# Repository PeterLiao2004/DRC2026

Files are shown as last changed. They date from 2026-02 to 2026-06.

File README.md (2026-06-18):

# DRC2026 Autonomous Car

Autonomous car project using a Raspberry Pi 5 for high-level autonomy and a Raspberry Pi Pico for low-level motor control.

## Repository Layout

```text
DRC2026/
+-- pi5_software/       High-level autonomy, perception, planning, and Pi-side services
+-- pico_firmware/      Low-level motor, encoder, and safety firmware for the Raspberry Pi Pico
+-- PCB/                KiCad PCB project, footprints, symbols, and fabrication outputs
+-- interfaces/         Communication contracts between the Pi 5, Pico, and hardware
+-- docs/               System architecture, bring-up notes, and design decisions
```

## System Roles

- **Raspberry Pi 5:** Main computer for camera processing, navigation, decision making, logging, and sending drive commands.
- **Raspberry Pi Pico:** Real-time controller for motors, encoders, watchdogs, and low-level safety behavior.
- **PCB:** Custom carrier/control board that connects power, Pico, motor driver, encoders, and expansion headers.

## Suggested Development Flow

1. Define or update the Pi-to-Pico protocol in `interfaces/`.
2. Implement low-level behavior in `pico_firmware/` and test it on the bench.
3. Implement high-level autonomy in `pi5_software/` against the same protocol.
4. Capture wiring, power, and bring-up notes in `docs/`.
5. Keep PCB source files and generated fabrication outputs in `PCB/`.

## Bring-Up Checklist

- Confirm PCB power rails before connecting the Pi 5 or Pico.
- Flash Pico firmware and verify motor disable/stop behavior first.
- Verify encoder telemetry with the car lifted off the ground.
- Connect Pi 5 software to the Pico protocol and test low-speed commands.
- Add autonomy features only after manual command and safety paths are reliable.

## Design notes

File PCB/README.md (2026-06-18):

# DRC Robot PCB

Custom PCB for a differential-drive robotics competition robot.

## Overview

This board integrates:

- Raspberry Pi Pico
- Dual motor driver
- 2S LiPo power input (VBAT)
- Regulated 5V logic rail
- Encoder headers
- LED expansion headers

Designed as a 2-layer PCB for low-cost fabrication.

## Power System

- **Battery:** 2S LiPo, about 7.4 V nominal
- **VBAT:** Motor power
- **+5V:** Logic and peripherals
- **GND:** Common ground plane

## KiCad Version

Created with **KiCad 9.0**.

## Usage

Clone the repository:

```bash
git clone https://github.com/PeterLiao2004/DRC2026.git
```

Open `DRC 2026.kicad_pro` in KiCad.

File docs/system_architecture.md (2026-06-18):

# System Architecture

## Overview

The car is split into a high-level computer and a low-level controller.

```text
Camera/Sensors -> Raspberry Pi 5 -> Pi/Pico Protocol -> Raspberry Pi Pico -> Motor Driver -> Motors
                                                     <- Telemetry/Encoders <-
```

## Raspberry Pi 5

- Runs autonomy and higher-level control loops.
- Handles sensors that do not need hard real-time timing.
- Sends desired motion commands to the Pico.
- Logs system state for debugging.

## Raspberry Pi Pico

- Runs timing-sensitive motor and encoder logic.
- Owns fail-safe motor shutdown.
- Reports encoder and motor telemetry back to the Pi 5.
- Should remain simple and deterministic.

## PCB

- Carries the Pico and motor-driver wiring.
- Provides power distribution and regulated logic rails.
- Exposes encoder and expansion connectors.
- Stores fabrication outputs under `PCB/gerbers/`.

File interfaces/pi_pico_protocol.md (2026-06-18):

# Pi 5 to Pico Protocol

Initial communication contract between the Raspberry Pi 5 and Raspberry Pi Pico.

## Link

- **Physical link:** USB serial or UART.
- **Owner:** Pi 5 sends commands, Pico enforces timing and safety.
- **Safety rule:** The Pico must stop the motors if valid commands are not received before the watchdog timeout.

## Command Direction

Pi 5 -> Pico:

```text
DRIVE left_speed right_speed
STOP
PING
```

Pico -> Pi 5:

```text
OK
ERR code message
TELEM left_ticks right_ticks left_pwm right_pwm battery_mv
PONG
```

## Field Notes

- `left_speed` and `right_speed` should start as normalized values from `-1.0` to `1.0`.
- The Pico should clamp all motor outputs to configured limits.
- Add a sequence number or checksum before relying on this link during autonomous operation.
- Keep this document updated before changing either implementation.

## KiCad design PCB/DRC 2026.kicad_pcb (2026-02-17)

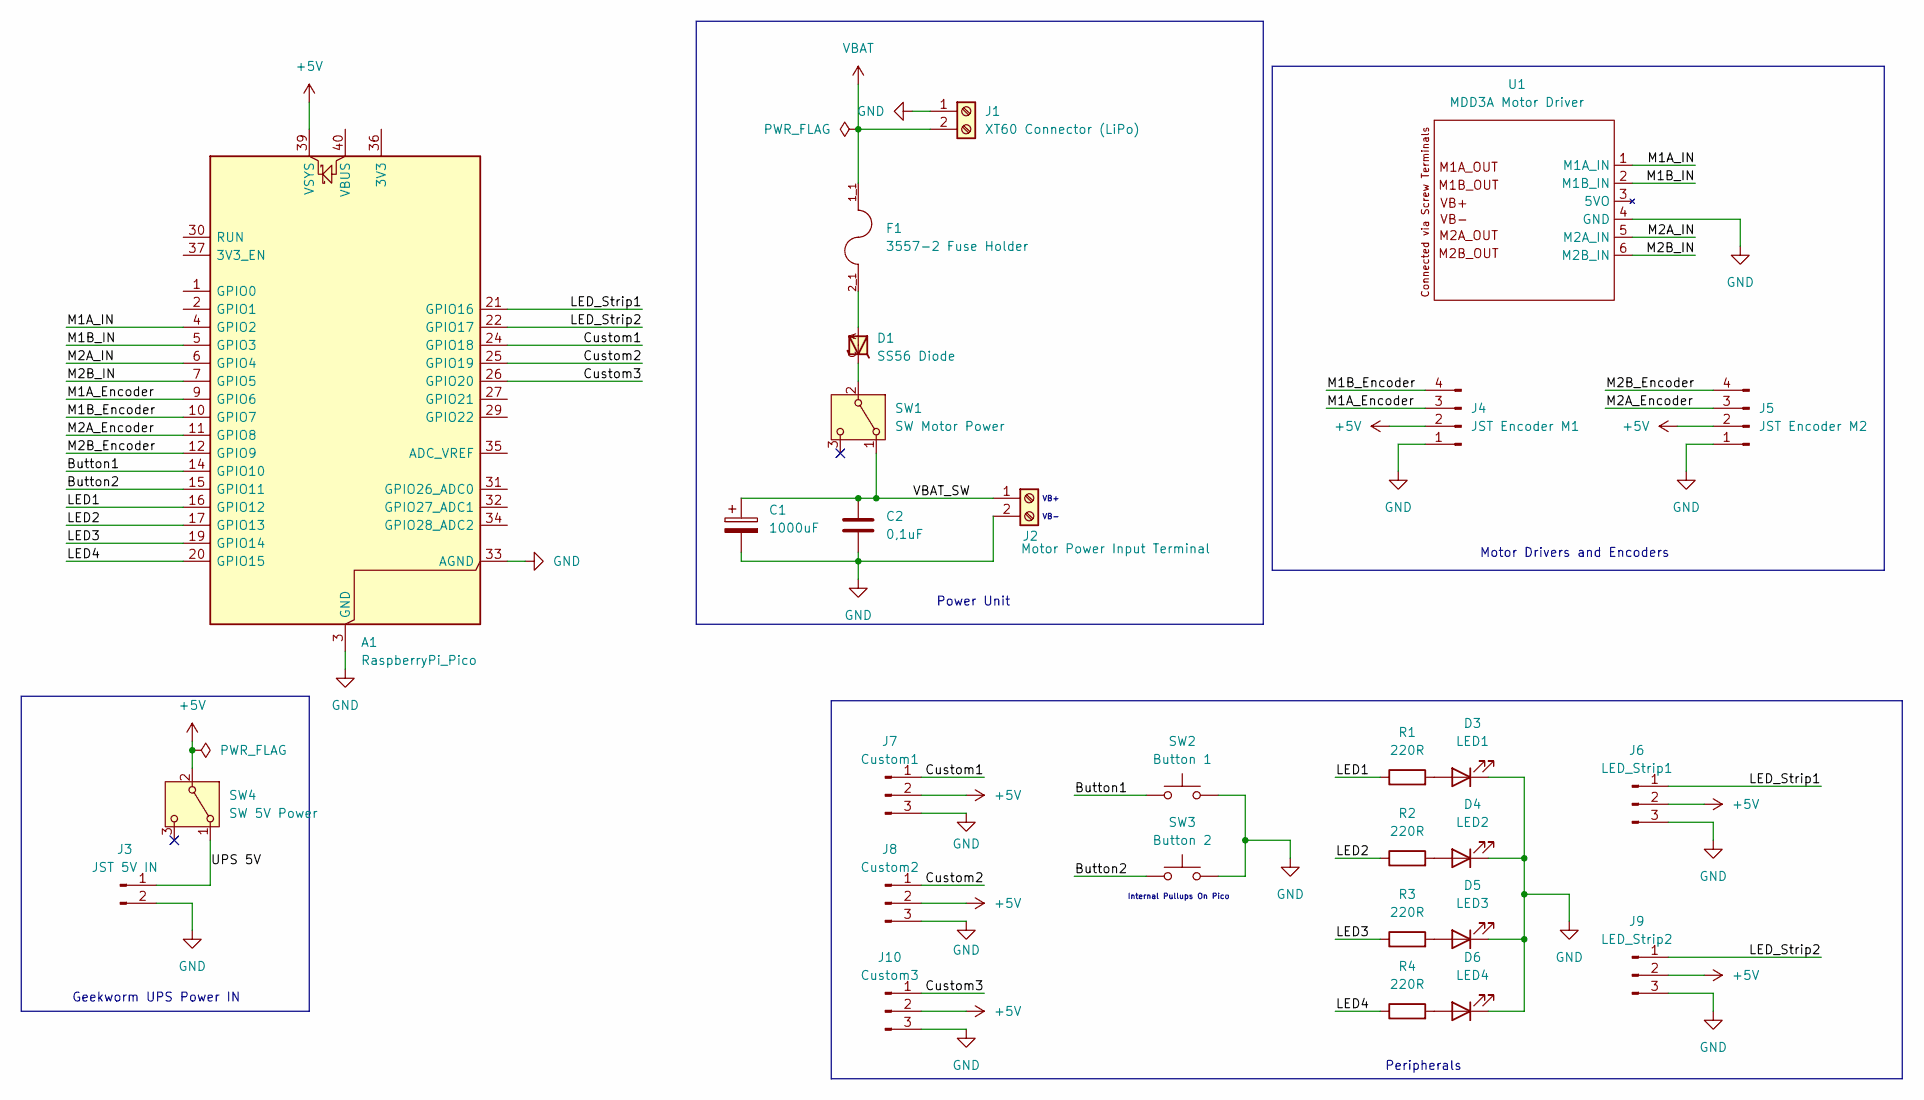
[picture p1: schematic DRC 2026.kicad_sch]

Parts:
A1: RaspberryPi_Pico; RaspberryPi_Pico_Dual_Header
C1: 1000uF; Capacitor_35PK1000MEFC10X20
C2: 0,1uF; CAPRR508W54L508T381H660
D1: SS56 Diode
D3: LED1; LED_D5.0mm
D4: LED2; LED_D5.0mm
D5: LED3; LED_D5.0mm
D6: LED4; LED_D5.0mm
F1: 3557-2 Fuse Holder; FUSE_3557-2; PARTREV D
J1: XT60 Connector (LiPo); AMASS_XT60PW-M_1x02_P7.20mm_Horizontal
J2: Motor Power Input Terminal; TerminalBlock_CUI_TB007-508-02_1x02_P5.08mm_Horizontal
J3: JST 5V IN; JST_XH_B2B-XH-A_1x02_P2.50mm_Vertical
J4: JST Encoder M1; JST_XH_B4B-XH-A_1x04_P2.50mm_Vertical
J5: JST Encoder M2; JST_XH_B4B-XH-A_1x04_P2.50mm_Vertical
J6: LED_Strip1; PinHeader_1x03_P2.54mm_Vertical
J7: Custom1; PinHeader_1x03_P2.54mm_Vertical
J8: Custom2; PinHeader_1x03_P2.54mm_Vertical
J9: LED_Strip2; PinHeader_1x03_P2.54mm_Vertical
J10: Custom3; PinHeader_1x03_P2.54mm_Vertical
R1, R2, R3, R4: 220R; R_0805_2012Metric_Pad1.20x1.40mm_HandSolder
SW1: SW Motor Power; SW_500SSP1S2M2QEA
SW2: Button 1; SW_PUSH_6mm
SW3: Button 2; SW_PUSH_6mm
SW4: SW 5V Power; SW_500SSP1S2M2QEA
U1: MDD3A Motor Driver

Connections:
+5V: A1.39 (VSYS), J4.2, J5.2, J6.2, J7.2, J8.2, J9.2, J10.2, SW4.2 (B)
/Button1: A1.14 (GPIO10), SW2.1
/Button2: A1.15 (GPIO11), SW3.1
/Custom1: A1.24 (GPIO18), J7.1
/Custom2: A1.25 (GPIO19), J8.1
/Custom3: A1.26 (GPIO20), J10.1
/LED1: A1.16 (GPIO12), R1.1
/LED2: A1.17 (GPIO13), R2.1
/LED3: A1.19 (GPIO14), R3.1
/LED4: A1.20 (GPIO15), R4.1
/LED_Strip1: A1.21 (GPIO16), J6.1
/LED_Strip2: A1.22 (GPIO17), J9.1
/M1A_Encoder: A1.9 (GPIO6), J4.3
/M1A_IN: A1.4 (GPIO2), U1.1 (M1A_IN)
/M1B_Encoder: A1.10 (GPIO7), J4.4
/M1B_IN: A1.5 (GPIO3), U1.2 (M1B_IN)
/M2A_Encoder: A1.11 (GPIO8), J5.3
/M2A_IN: A1.6 (GPIO4), U1.5 (M2A_IN)
/M2B_Encoder: A1.12 (GPIO9), J5.4
/M2B_IN: A1.7 (GPIO5), U1.6 (M2B_IN)
/UPS 5V: J3.1, SW4.1 (A)
/VBAT_SW: C1.1, C2.1, J2.1, SW1.1 (A); also elsewhere on the board
GND: A1.3 (GND), A1.8 (GND), A1.13 (GND), A1.18 (GND), A1.23 (GND), A1.28 (GND), A1.33 (AGND), A1.38 (GND), C1.2, C2.2, D3.1 (K), D4.1 (K), D5.1 (K), D6.1 (K), J1.1, J2.2, J3.2, J4.1, J5.1, J6.3, J7.3, J8.3, J9.3, J10.3, SW2.2, SW3.2, U1.4 (GND); also elsewhere on the board
unnamed: D1.A, F1.2_1, F1.2_2
unnamed: D3.2 (A), R1.2
unnamed: D4.2 (A), R2.2
unnamed: D5.2 (A), R3.2
unnamed: D6.2 (A), R4.2
unnamed 28: D1.C, SW1.2 (B); also elsewhere on the board
VBAT: F1.1_1, F1.1_2, J1.2; also elsewhere on the board

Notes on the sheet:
Power Unit
VB-
Internal Pullups On Pico
Peripherals
Geekworm UPS Power IN
VB+
Motor Drivers and Encoders

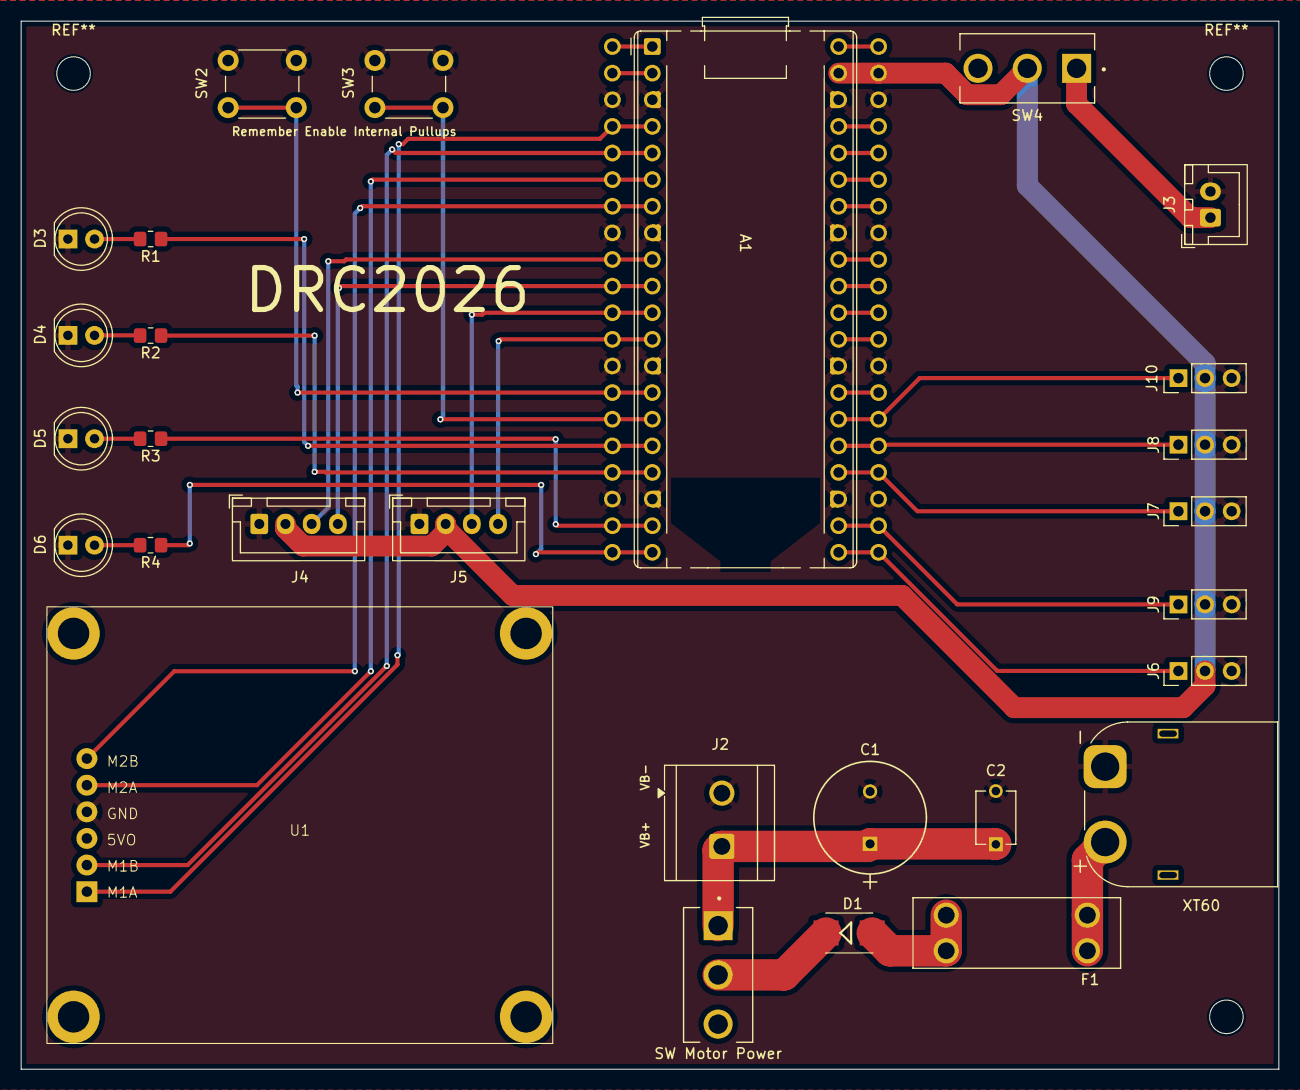
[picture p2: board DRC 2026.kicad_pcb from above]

Board: 2 copper layers, 120.0 x 100.0 mm, 28 parts (0 on the bottom side), 30 nets.

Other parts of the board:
SW Motor Power: SW Motor Power; SW_500SSP1S2M2QEA
XT60: XT60 Connector (LiPo); AMASS_XT60PW-M_1x02_P7.20mm_Horizontal

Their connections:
/VBAT_SW: SW Motor Power.1 (A); also elsewhere on the board
GND: XT60.1; also elsewhere on the board
unnamed 28: SW Motor Power.2 (B); also elsewhere on the board
VBAT: XT60.2; also elsewhere on the board

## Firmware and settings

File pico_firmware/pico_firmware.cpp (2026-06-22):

#include "pico/stdlib.h"
#include "hardware/pwm.h"
#include "hardware/sync.h"
#include <stdio.h>
#include <cstdlib>
#include <cstdint>
#include <cstring>

//----------------Hardware Definitions------------------//
// Wheel Diameter
#define WHEEL_DIAMETER_MM 65
#define WHEEL_CIRCUMFERENCE_MM (WHEEL_DIAMETER_MM * 3.14159)
#define MM_PER_REV WHEEL_CIRCUMFERENCE_MM

// Wheelbase (distance between the two wheels)
#define WHEELBASE_MM 240

//--------------------GPIO Pin Definitions------------------//
// Motor driver pins
#define M1A 2
#define M1B 3
#define M2A 4
#define M2B 5

// Motor Encoder Pins
#define M1_ENCODER_A 6
#define M1_ENCODER_B 7
#define M2_ENCODER_A 8
#define M2_ENCODER_B 9

//Buttons
#define BUTTON1 10
#define BUTTON2 11

//LED Pins
#define LED1 12
#define LED2 13
#define LED3 14
#define LED4 15

//LED Strip Pins
#define LED_STRIP1 16
#define LED_STRIP2 17

//Custom Pins (for future use, e.g. sensors)
#define CUSTOM1 18
#define CUSTOM2 19
#define CUSTOM3 20
//--------------------Control Parameters------------------//
// PWM settings
#define PWM_WRAP 1000
#define MIN_PWM 350
#define MAX_PWM 1000
#define ENCODER_COUNTS_PER_REV 893
#define RPM_SAMPLE_MS 500
#define SAMPLES_PER_LEVEL 8

// PID control settings
#define KP 0.2f
#define BASE_SPEED_PERCENT 30

// Signed x4 quadrature counts (every A/B edge is counted).
volatile int32_t m1_encoder_count = 0;
volatile int32_t m2_encoder_count = 0;
volatile uint8_t m1_encoder_state = 0;
volatile uint8_t m2_encoder_state = 0;

// Previous AB state in the upper two bits, current AB state in the lower two.
// Invalid transitions (usually contact bounce or missed edges) contribute zero.
static const int8_t QUADRATURE_DELTA[16] = {
     0, -1,  1,  0,
     1,  0,  0, -1,
    -1,  0,  0,  1,
     0,  1, -1,  0
};

//---------------------Serial communication------------------//
#define SERIAL_BUFFER_SIZE 32


//=====================Functions============================//

//--------------------Serial Communication------------------//
int clamp_int(int value, int min_value, int max_value) {
    if (value < min_value) return min_value;
    if (value > max_value) return max_value;
    return value;
}

bool read_serial_line(char *buffer, int buffer_size) {
    static int index = 0;

    int ch = getchar_timeout_us(0);

    while (ch != PICO_ERROR_TIMEOUT) {
        if (ch == '\n' || ch == '\r') {
            if (index > 0) {
                buffer[index] = '\0';
                index = 0;
                return true;
            }
        } else {
            if (index < buffer_size - 1) {
                buffer[index++] = (char)ch;
            } else {
                // Buffer overflow protection
                index = 0;
            }
        }

        ch = getchar_timeout_us(0);
    }

    return false;
}

//-------------------Encoder Handling------------------//
// This reads the two encoder pins and turns them into one number from 0 to 3.
uint8_t read_encoder_state(uint a_pin, uint b_pin) {
    return static_cast<uint8_t>((gpio_get(a_pin) << 1) | gpio_get(b_pin));
}
// Encoder GPIO ISR: automatically runs whenever an encoder pin changes. Updates encoder counts and state.
void encoder_gpio_callback(uint gpio, uint32_t events) {
    (void)events;

    if (gpio == M1_ENCODER_A || gpio == M1_ENCODER_B) {
        uint8_t current = read_encoder_state(M1_ENCODER_A, M1_ENCODER_B);
        m1_encoder_count += QUADRATURE_DELTA[(m1_encoder_state << 2) | current];
        m1_encoder_state = current;
    } else if (gpio == M2_ENCODER_A || gpio == M2_ENCODER_B) {
        uint8_t current = read_encoder_state(M2_ENCODER_A, M2_ENCODER_B);
        m2_encoder_count += QUADRATURE_DELTA[(m2_encoder_state << 2) | current];
        m2_encoder_state = current;
    }
}

// Initializes encoder GPIOs and sets up interrupts to track encoder counts.
void setup_encoders() {
    const uint pins[] = {M1_ENCODER_A, M1_ENCODER_B, M2_ENCODER_A, M2_ENCODER_B};

    for (uint pin : pins) {
        gpio_init(pin);
        gpio_set_dir(pin, GPIO_IN);
        gpio_pull_up(pin);
    }

    m1_encoder_state = read_encoder_state(M1_ENCODER_A, M1_ENCODER_B);
    m2_encoder_state = read_encoder_state(M2_ENCODER_A, M2_ENCODER_B);

    const uint32_t edges = GPIO_IRQ_EDGE_RISE | GPIO_IRQ_EDGE_FALL;
    gpio_set_irq_enabled_with_callback(M1_ENCODER_A, edges, true, &encoder_gpio_callback);
    gpio_set_irq_enabled(M1_ENCODER_B, edges, true);
    gpio_set_irq_enabled(M2_ENCODER_A, edges, true);
    gpio_set_irq_enabled(M2_ENCODER_B, edges, true);
}

// Atomically reads the encoder counts. Should be called at a regular interval to track speed.
void read_encoder_counts(int32_t &m1, int32_t &m2) {
    uint32_t irq_state = save_and_disable_interrupts();
    m1 = m1_encoder_count;
    m2 = m2_encoder_count;
    restore_interrupts(irq_state);
}

// Converts change in encoder counts over a sample period to RPM x10 (to avoid floating-point).
int32_t counts_to_rpm_x10(int32_t delta_counts, uint32_t sample_ms) {
    // RPM x10 avoids relying on floating-point printf support.
    int64_t magnitude = delta_counts < 0 ? -(int64_t)delta_counts : delta_counts;
    return static_cast<int32_t>((magnitude * 600000) /
                                (ENCODER_COUNTS_PER_REV * sample_ms));
}
//----------------------------------------------------//
//-------------------PWM/Motor Control------------------//

void setup_pwm_pin(uint pin) {
    gpio_set_function(pin, GPIO_FUNC_PWM);

    uint slice = pwm_gpio_to_slice_num(pin);
    pwm_set_wrap(slice, PWM_WRAP);
    pwm_set_enabled(slice, true);
}

void set_pwm(uint pin, int duty) {
    if (duty < 0) duty = 0;
    if (duty > PWM_WRAP) duty = PWM_WRAP;

    pwm_set_gpio_level(pin, duty);
}

int speed_to_pwm(int speed_percent) {
    // speed_percent range: 0 to 100
    if (speed_percent <= 0) return 0;
    if (speed_percent > 100) speed_percent = 100;

    return MIN_PWM + (speed_percent * (MAX_PWM - MIN_PWM)) / 100;
}

void motor1_set_percent(int speed_percent) {
    // Positive = forward, negative = reverse
    int pwm = speed_to_pwm(abs(speed_percent));

    if (speed_percent > 0) {
        set_pwm(M1A, pwm);
        set_pwm(M1B, 0);
    } else if (speed_percent < 0) {
        set_pwm(M1A, 0);
        set_pwm(M1B, pwm);
    } else {
        set_pwm(M1A, 0);
        set_pwm(M1B, 0);
    }
}

void motor2_set_percent(int speed_percent) {
    // Positive = forward, negative = reverse
    int pwm = speed_to_pwm(abs(speed_percent));

    if (speed_percent > 0) {
        set_pwm(M2A, pwm);
        set_pwm(M2B, 0);
    } else if (speed_percent < 0) {
        set_pwm(M2A, 0);
        set_pwm(M2B, pwm);
    } else {
        set_pwm(M2A, 0);
        set_pwm(M2B, 0);
    }
}
//-------------------High-Level Motor Control-----------------//

void stop_all() {
    motor1_set_percent(0);
    motor2_set_percent(0);
}

void drive_forward(int speed_percent) {
    motor1_set_percent(speed_percent);
    motor2_set_percent(speed_percent);
}

void drive_backward(int speed_percent) {
    motor1_set_percent(-speed_percent);
    motor2_set_percent(-speed_percent);
}

void turn_left(int speed_percent) {
    // Left turn: one motor backwards, one motor forwards
    motor1_set_percent(-speed_percent);
    motor2_set_percent(speed_percent);
}

void turn_right(int speed_percent) {
    // Right turn: one motor forwards, one motor backwards
    motor1_set_percent(speed_percent);
    motor2_set_percent(-speed_percent);
}

//-------------------PID Control ---------------------------------//
// This is a simple proportional controller that adjusts motor speeds based on an error value.
void drive_with_error(float error, int base_speed) {
    float Kp = KP;  // steering strength, tune this later

    int correction = static_cast<int>(Kp * error);

    int left_speed = base_speed - correction;
    int right_speed = base_speed + correction;

    // Clamp speeds to -100 to 100
    left_speed = clamp_int(left_speed, -100, 100);
    right_speed = clamp_int(right_speed, -100, 100);

    // Your motors are mounted opposite directions
    motor1_set_percent(left_speed);
    motor2_set_percent(right_speed);

    printf("error: %.2f, base: %d, left: %d, right: %d\n",
           error, base_speed, left_speed, right_speed);
}

//------------------------Testing/Helpers -------------------------//
// Helper function to print RPM in a human-friendly format.
void print_rpm(int motor, int32_t delta_counts) {
    int32_t rpm_x10 = counts_to_rpm_x10(delta_counts, RPM_SAMPLE_MS);
    printf("M%d: %ld counts, %ld.%01ld RPM",
           motor,
           static_cast<long>(delta_counts),
           static_cast<long>(rpm_x10 / 10),
           static_cast<long>(rpm_x10 % 10));
}

void run_drive_step(const char *name,
                    void (*movement)(int),
                    int speed_percent,
                    uint32_t duration_ms) {
    int32_t start_m1;
    int32_t start_m2;
    read_encoder_counts(start_m1, start_m2);

    printf("%s at %d%%\n", name, speed_percent);
    movement(speed_percent);
    sleep_ms(duration_ms);
    stop_all();

    int32_t end_m1;
    int32_t end_m2;
    read_encoder_counts(end_m1, end_m2);
    printf("Stopped - encoder change: M1 = %ld, M2 = %ld\n",
           static_cast<long>(end_m1 - start_m1),
           static_cast<long>(end_m2 - start_m2));

    sleep_ms(1000);
}

void run_drive_test() {
    constexpr int TEST_SPEED_PERCENT = 25;

    printf("\nDrive test starting. Keep the area clear.\n");
    sleep_ms(2000);

    run_drive_step("Forward", drive_forward, TEST_SPEED_PERCENT, 1500);
    run_drive_step("Backward", drive_backward, TEST_SPEED_PERCENT, 1500);
    run_drive_step("Turn left", turn_left, TEST_SPEED_PERCENT, 1000);
    run_drive_step("Turn right", turn_right, TEST_SPEED_PERCENT, 1000);

    stop_all();
    printf("Drive test complete. Press R to run it again.\n");
}

// Dummy error values for testing P Control
const float dummy_errors[] = {
    0.0f,    // straight
    0.2f,    // slight correction one way
    0.5f,    // stronger correction one way
    0.0f,    // straight again
    -0.2f,   // slight correction other way
    -0.5f,   // stronger correction other way
    0.0f     // straight
};

const int num_errors = sizeof(dummy_errors) / sizeof(dummy_errors[0]);
//------------------------Main Loop-------------------------//
int main() {
    // Initialize stdio for printf debugging (over USB).
    stdio_init_all();

    // Set up PWM pins and encoder GPIOs with interrupts.
    setup_pwm_pin(M1A);
    setup_pwm_pin(M1B);
    setup_pwm_pin(M2A);
    setup_pwm_pin(M2B);
    setup_encoders();

    // Initialize all motors to stopped
    stop_all();
    sleep_ms(3000);

    printf("Pico ready. Send values from -100 to 100.\n");

    char line[SERIAL_BUFFER_SIZE];

    while (true) {
        if (read_serial_line(line, SERIAL_BUFFER_SIZE)) {
            printf("Received from Pi: %s\n", line);

            int value = atoi(line);
            value = clamp_int(value, -100, 100);


            drive_with_error(value, BASE_SPEED_PERCENT);
        }

        sleep_ms(5);
    }
}

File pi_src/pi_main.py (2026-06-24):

import cv2
import numpy as np
import serial
import time
from collections import deque
from picamera2 import Picamera2

# ------------------------------
# Serial settings (to Pico)
# ------------------------------
PORT = "/dev/ttyACM0"
BAUD = 115200
ser = serial.Serial(PORT, BAUD, timeout=1)

# -----------------------------
# Camera settings
# -----------------------------
FRAME_W = 960
FRAME_H = 540
FPS_TARGET = 40

picam2 = Picamera2()

config = picam2.create_video_configuration(
    main={"format": "RGB888", "size": (FRAME_W, FRAME_H)},
    controls={"FrameRate": FPS_TARGET}
)

picam2.configure(config)

# picam2.set_controls({
#     "ExposureTime": 13000,
#     "AnalogueGain": 2.8,
#     "ColourGains": (2.1, 1.6)
# })
picam2.set_controls({"ExposureTime": 9000, "AnalogueGain": 2.0, "ColourGains": (2.1, 1.9)})

picam2.start()

# -----------------------------
# HSV thresholds
# -----------------------------

# SOFIA HOUSE:
# # Yellow line, left side
# YELLOW_LOWER = np.array([19, 176, 108])
# YELLOW_UPPER = np.array([29, 255, 182])

# BLUE_LOWER = np.array([0, 0, 0])
# BLUE_UPPER = np.array([171, 206, 70])

# # Arrow thresholds from your arrow detection code
# ARROW_LOWER = np.array([10, 97, 15])
# ARROW_UPPER = np.array([31, 172, 120])

# # Green Line, start/stop
# GREEN_LOWER = np.array([19, 134, 19])
# GREEN_UPPER = np.array([59, 209, 104])

# UNI TRACK:
YELLOW_LOWER = np.array([25, 47, 174])
YELLOW_UPPER = np.array([32, 169, 255])

BLUE_LOWER = np.array([68, 18, 169])
BLUE_UPPER = np.array([107, 224, 255])

GREEN_LOWER = np.array([41, 28, 183])
GREEN_UPPER = np.array([84, 129, 255])

PURPLE_LOWER = np.array([155, 73, 70])
PURPLE_UPPER = np.array([179, 173, 166])

ARROW_LOWER = np.array([20, 16, 73])
ARROW_UPPER = np.array([77, 47, 166])

# -----------------------------
# Line following settings
# -----------------------------
LOOKAHEAD_Y = int(FRAME_H * 0.58)
BAND_HEIGHT = 100
MIN_PIXELS_LINE = 50

# -----------------------------
# Purple obstacle settings
# -----------------------------
PURPLE_MIN_AREA = 900
PURPLE_MIN_W = 25
PURPLE_MIN_H = 25

# Only care about obstacles around the driving/lookahead area
PURPLE_ROI_Y1 = int(FRAME_H * 0.35)
PURPLE_ROI_Y2 = int(FRAME_H * 0.95)

# How close the purple cube must be to the lookahead band to affect steering
PURPLE_LOOKAHEAD_MARGIN = 120

# Extra gap between robot target path and purple block
OBSTACLE_CLEARANCE = 70

# Keep the chosen obstacle side stable so it does not flip every frame
OBSTACLE_LATCH_TIME = 0.7

obstacle_avoid_side = None
last_obstacle_seen_time = -999.0

OBSTACLE_SIDE_DEADBAND = 45

# ------------------------
# Driving settings
# ------------------------
last_error = 0.0
last_lane_width = None
last_seen_line = "NONE"

# If only one line is visible and we cannot estimate centre properly,
# force a recovery turn instead of driving with an old error.
RECOVERY_ERROR = 0.85

# Used to stop obviously bad lane-width updates
MIN_VALID_LANE_WIDTH = int(FRAME_W * 0.20)
MAX_VALID_LANE_WIDTH = int(FRAME_W * 0.98)

# SLOW, working pretty well
# current_speed = 60
# base_speed = 60
# arrow_confirming_speed = 15
# arrow_speed = 45
# RECOVERY_SPEED = 28
# obstacle_speed = 30

# GREEN_STOP_DELAY = 2.5

# Kp = 0.2
# Ki = 0
# Kd = 0.11

# Medium speed, pretty decent but a little dodgy
# current_speed = 70
# base_speed = 70
# arrow_confirming_speed = 30
# arrow_speed = 55
# RECOVERY_SPEED = 30
# obstacle_speed = 30

# GREEN_STOP_DELAY = 2.0

# Kp = 0.25
# Ki = 0
# Kd = 0.11

# Fast! Works pretty good!
# current_speed = 90
# base_speed = 90
# arrow_confirming_speed = 35
# arrow_speed = 60
# RECOVERY_SPEED = 35
# obstacle_speed = 40

# GREEN_STOP_DELAY = 1.6

# Kp = 0.3
# Ki = 0
# Kd = 0.11

# Very Fast!!!!
current_speed = 100
base_speed = 100
arrow_confirming_speed = 40
arrow_speed = 70
RECOVERY_SPEED = 45
obstacle_speed = 55

GREEN_STOP_DELAY = 1.6

Kp = 0.4
Ki = 0
Kd = 0.18

# Ignore green for the first 30 seconds after starting
GREEN_IGNORE_TIME = 20

# ------------------------
# Green settings
# ------------------------

green_seen_start_time = None
robot_stopped_by_green = False

robot_start_time = time.time()

# -----------------------------
# Arrow detection settings
# -----------------------------

# Minimum arrow blob size
MIN_AREA_FRAC = 0.004
MIN_AREA = int(FRAME_W * FRAME_H * MIN_AREA_FRAC)

# Maximum arrow blob size
# Rejects huge blobs like the floor/ground being detected as arrow colour.
MAX_AREA_FRAC = 0.08
MAX_AREA = int(FRAME_W * FRAME_H * MAX_AREA_FRAC)

# Mask cleaning
ARROW_KERNEL = np.ones((3, 3), np.uint8)

# How far the arrow tip needs to be from the centre
MIN_TIP_OFFSET_FRAC = 0.12

# Only search for arrows in this region of the image
# This helps stop random background objects being detected
ARROW_ROI_X1 = int(FRAME_W * 0.10)
ARROW_ROI_X2 = int(FRAME_W * 0.90)
ARROW_ROI_Y1 = int(FRAME_H * 0.45)
ARROW_ROI_Y2 = int(FRAME_H * 1.00)

# Basic shape filtering
MIN_ARROW_W = 35
MIN_ARROW_H = 25
MIN_FILL_RATIO = 0.12
MAX_FILL_RATIO = 0.85
MIN_ASPECT_RATIO = 0.5
MAX_ASPECT_RATIO = 4.0

# Arrow bias timing
ARROW_WAIT_TIME = 0.8
ARROW_STRONG_TIME = 1.2
ARROW_MODERATE_TIME = 1.7
ARROW_WEAK_TIME = 1.2

# Arrow bias strength
# These values are normalised error values.
# 0.95 becomes about 95 after multiplying by 100.
ARROW_WAIT_BIAS = 0.02
ARROW_STRONG_BIAS = 0.85
ARROW_MODERATE_BIAS = 0.5
ARROW_WEAK_BIAS = 0.2

# Positive error should turn right.
# If the robot turns the wrong way, change this to -1.
ARROW_RIGHT_SIGN = 1

# Arrow confirmation system
ARROW_CONFIRM_FRAMES = 5          # same direction must be seen this many frames
ARROW_CONFIRM_TIMEOUT = 1.0       # cancel confirmation if it takes too long
ARROW_LOST_TIMEOUT = 0.25         # allow brief missed frames while confirming

# Prevent the same arrow from instantly retriggering
ARROW_COOLDOWN_TIME = 1.0

# Pending arrow confirmation state
pending_arrow_direction = None
pending_arrow_count = 0
pending_arrow_start_time = None
last_pending_arrow_seen_time = None

# Confirmed arrow bias state
arrow_bias_start_time = None
arrow_bias_direction = None
last_arrow_trigger_time = -999.0

# -----------------------------
# FPS settings
# -----------------------------
prev_time = time.time()
fps = 0.0


# ============================================================
# Helper functions
# ============================================================

def mask_and_clean(hsv, lower, upper, kernel_size=5):
    """
    Creates a colour mask and cleans small noise.
    Used for the yellow and blue line masks.
    """

    mask = cv2.inRange(hsv, lower, upper)

    kernel = np.ones((kernel_size, kernel_size), np.uint8)
    mask = cv2.morphologyEx(mask, cv2.MORPH_OPEN, kernel)

    return mask
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

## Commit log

2026-02-17 Initial commit - schematic + pcb base
    [DRC 2026-B_Mask.gbr, DRC 2026-B_Paste.gbr, DRC 2026-B_Silkscreen.gbr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]
2026-02-17 Add README for DRC Robot PCB project
    Added detailed project overview and specifications for DRC Robot PCB.
2026-02-17 Revise README for DRC Robot PCB
    Updated README to improve clarity and structure, including a new usage section with cloning instructions.
2026-06-18 Changed folder structure
    [DRC 2026-B_Mask.gbr, DRC 2026-B_Paste.gbr, DRC 2026-B_Silkscreen.gbr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]
2026-06-18 Pico Firmware SDK setup
2026-06-19 Basic motor control
2026-06-19 Basic motor PWM control
2026-06-19 Basic motor driving demo
2026-06-20 Basic motor movement with encoder readings
2026-06-22 PICO: Updated motor control defines
2026-06-22 PICO: comments
2026-06-22 PICO: more comments, motor drive test
2026-06-22 PICO: motor direction change
2026-06-22 Add code to find lines and calculate centre error
    [Get_line_errors.py]
2026-06-22 PICO: corrected motor direction
    [pico_firmware.cpp]
2026-06-22 PICO: simple P control
2026-06-22 PICO: Draft, serial control
2026-06-22 PICO: P control movement done
2026-06-23 Sends serial commands to pico
2026-06-23 Fixed thresholds, changed serial output
    [Errors_to_serial.py]
2026-06-23 Added merged line and arrow code, still buggy
    [Lines_and_arrows.py]
2026-06-23 Lines at uni, arrow slow and confirm, PID serial
2026-06-23 Green follows line, arrow better not perfect, PID tuned with shell
2026-06-24 Kinda working code - track from @1:30
2026-06-24 Code working decent, adjusted camera band lower (fixed corner cutting)
    [pi_main.py]
2026-06-24 CODE WORKING (pretty well) - fixed obstacle avoidance)
    [pi_main.py]
